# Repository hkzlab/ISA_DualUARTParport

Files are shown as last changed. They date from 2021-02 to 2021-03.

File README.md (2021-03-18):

# Dual UART + Parallel port ISA adapter

## Introduction

This board adds a parallel port and two serial (RS232) ports to computers with a free ISA slot.

The schematics of this board is heavily inspired by the parallel port schematics found in the IBM 5150 Technical Reference, with just a few
changes (IRQ level triggering and configurable port directionality) and by Sergey's floppy/serial controller.

Both serial ports and the parallel port addressing/IRQs are configurable.

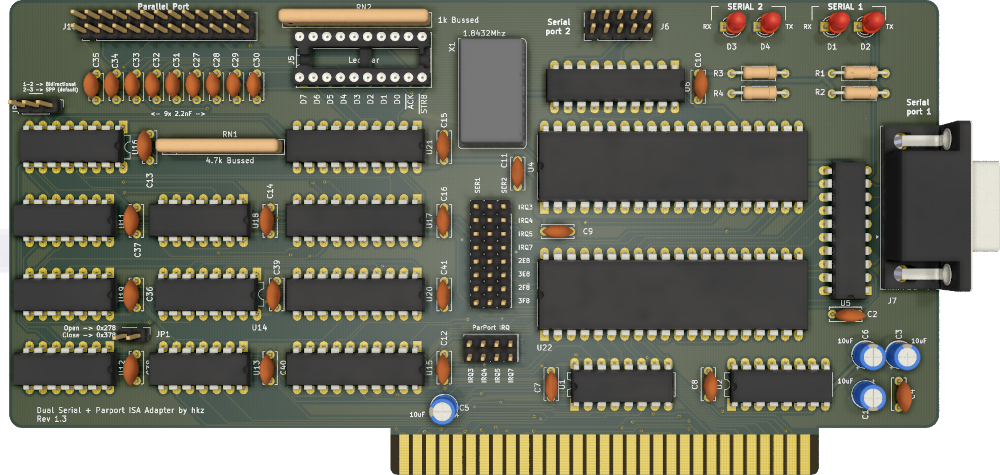
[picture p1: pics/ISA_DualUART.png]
Rev. 1.3 PCB


### Disclaimer

I take NO responsibility for what happens if you decide to build and use this card. Your computer might crash, catch fire or be destroyed in other nasty ways.
Also, as this card is mostly based on the work of others, You're encourauged to take what you deem fit from this, and use it in your projects!

## Configuration

### Parallel port

#### Addressing

- 0x278: Leave JP1 open
- 0x378: Close JP1

#### IRQ

Parallel port interrupt number can be selected by placing a single vertical jumper on the **ParPort IRQ** block.

For example, a jumper placed on the last column of that block, will set the IRQ for the parallel port to number 7.

#### Directionality

The parallel port can be configured as an old style 4bit, monodirectional, parallel port by jumpering pins 2-3 of JP2.
PS/2 style bidirectional port can be configured by jumpering pins 1-2.

### Serial ports

IRQ and addressing of serial ports can be configured by properly jumpering the 3x8 jumper block at the center of the board.

IRQ selection is performed by the first 4 rows of the block: placing an horizontal jumper between columns 1-2 will select IRQ for the first serial port, between columns 2-3 will select
the IRQ for the second serial port.

The same principle applies for the IO address, selected by the last 4 rows of the block: jumpers between column 1-2 will select an address for port 1, and between column 2-3 for port 2.

#### Example

To select IO at 0x3F8 and IRQ4 for port 1, connect a jumper on 2nd row, first two columns, and another jumper on 8th row, column 1-2

## Bill of Materials

All ICs are in DIP package.

- 4x ~2.2k 1/4W resistors (**optional**, R1-R4). **These resistors will be on the TTL RX/TX lines**. To avoid loading them too much, use high-brightness leds and the highest resistor value you can use that still gives enough brightness!
- 4x 3mm LEDs (2x for UART RX indicators, 2x for TX) (**optional**)
- 1x 1.8432Mhz oscillator. DIP14 or DIP8
- 1x 8x4.7k bussed resistor array (9 pin)
- 1x 10x1.5k bussed resistor array (11 pin) (**optional**)
- 1x 10x LED bar, DIP20 (**optional**, socket this!)
- 8x 2.2nF / 25V ceramic capacitors, 5mm pitch
- 18x 100nF / 50v ceramic capacitors, 5mm pitch
- 4x 10uF / 50v electrolytic caps
- 2x 16C550 UARTs (16C450/16C650/16C750 should work, but are untested) in DIP40 format
- 2x 74HCT/LS138
- 2x 75C185
- 1x 74LS245
- 1x 74LS240
- 1x 74LS374
- 1x 74LS244
- 1x 74LS02
- 1x 74LS155
- 1x 74LS05
- 1x 74LS174
- 1x 74LS30
- 1x 74LS125
- 1x 74LS86
- 1x 2x13 pin header, 2.54mm
- 1x 2x4 pin header, 2.54mm
- 1x 2x8 pin header, 2.54mm
- 1x 1x8 pin header, 2.54mm
- 1x 1x2 pin header, 2.54mm
- 1x 1x3 pin header, 2.54mm
- 1x DB9 male, right angle, PCB mount (http://www.mouser.com/search/refine.aspx?Keyword=806-K22X-E9P-NJ15-99)
- 1x ISA card bracket - Keystone 9200-1 (http://www.mouser.com/ProductDetail/Keystone-Electronics/9200-1/?qs=sGAEpiMZZMsQtlBhqKq43VLJ3wppkop5) 

## Building notes

I **strongly advise AGAINST** soldering the LED bar for the parallel port: **socket it!** It is useful for debugging or to get some blinkenlights, but it loads the data pins, and some devices connected to the port might not like it. Socketing it will allow for a quick removal in case it becomes necessary.

RN2 depends on how bright you wish the LED bar to be, and how much load you want to put on the parallel port data pins. I usually fit an 1.5k resistor array.

## Credits

Thanks to [Sergey](http://www.malinov.com/Home/sergeys-projects) for all his projects!

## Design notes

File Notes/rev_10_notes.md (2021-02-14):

# Revision 1.0 Notes

## Parallel port header

The parallel port header is not standard in revision 1.0, and requires a custom cable to be made.
The pinout uses an odd-even scheme. A schematic looking at the male header on the front of the board:

```text
25 23 21 19 17 15 13 11 09 07 05 03 01
26 24 22 20 18 16 14 12 10 08 06 04 02
```

## Parallel port IRQ

Revision 1.0 board follows the IBM 5150 Technical Manual, but the parallel port presented there has a now out-of-standard IRQ triggering system. To bring it back in line with the now standard behavior, perform the following modification:

1. Cut the trace leading to pin 12 of U19. The best place to do this is right under the solder pad. Pay attention not to interrupt the trace hidden under the silkscreen
2. Bridge pin 12 of U19 with pin 13 of U12 with a piece of wire
3. Solder a pull-up resistor (4.7k ohm) between pin 12 of U19 and VCC (use the filter cap nearby).

Picture for reference.

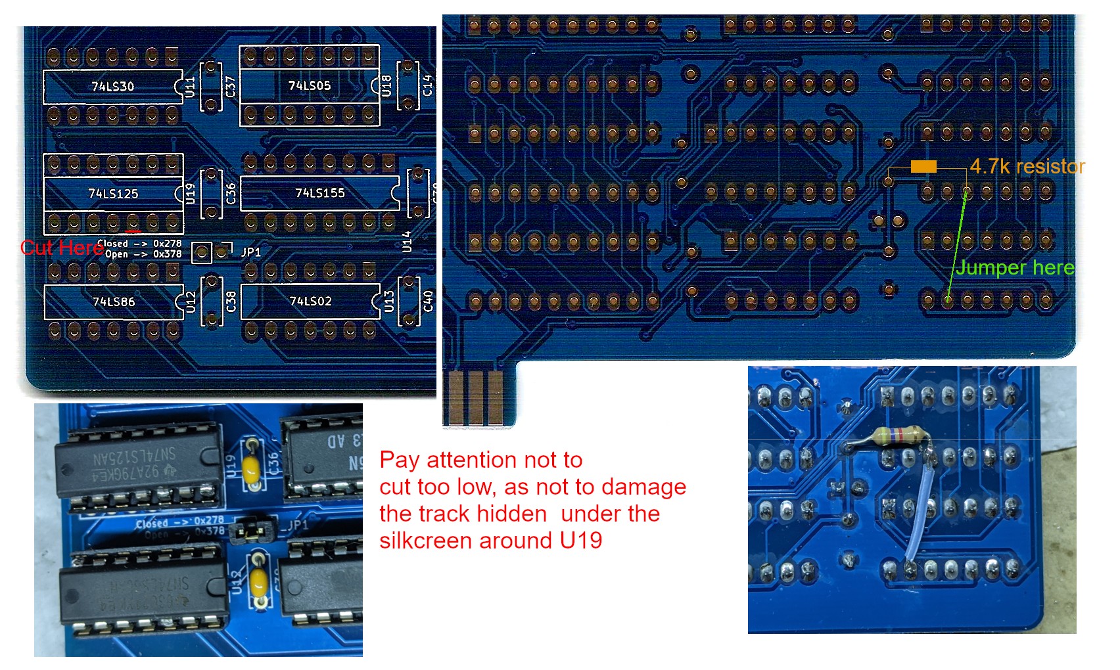
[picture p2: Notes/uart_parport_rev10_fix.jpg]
IRQ Mod


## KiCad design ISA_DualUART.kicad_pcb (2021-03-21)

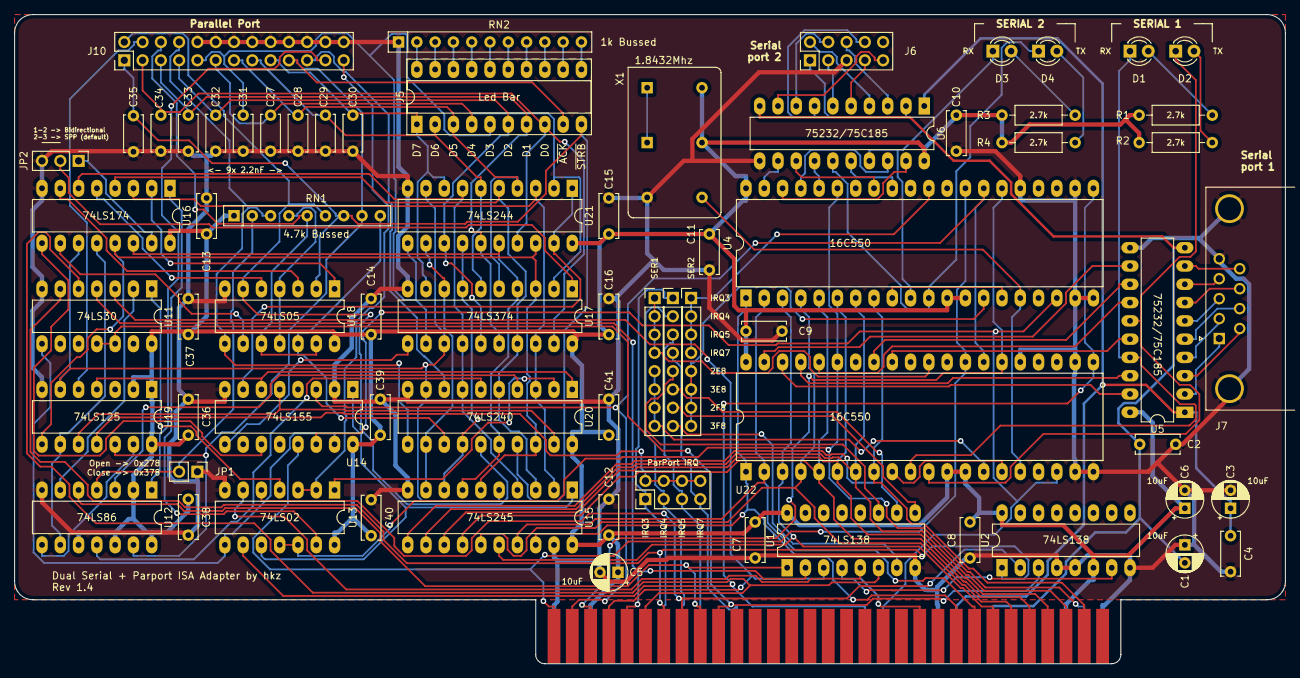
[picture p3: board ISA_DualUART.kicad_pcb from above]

Board: 2 copper layers, 176.5 x 90.2 mm, 70 parts (0 on the bottom side), 138 nets.

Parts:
C1, C3, C5, C6: 10uF; CP_Radial_D5.0mm_P2.50mm
C2, C4, C7, C8, C9, C10, C11, C12, C13, C14, C15, C16, C36, C37, C38, C39, C40, C41: 100nF; C_Disc_D6.0mm_W2.5mm_P5.00mm
C27, C28, C29, C30, C31, C32, C33, C34, C35: 2.2nF; C_Disc_D5.0mm_W2.5mm_P5.00mm
D1: LED RX1; LED_D3.0mm
D2: LED TX1; LED_D3.0mm
D3: LED RX2; LED_D3.0mm
D4: LED TX2; LED_D3.0mm
J1: ISA BUS; Conn_Edge_PCB_ISA8
J2: ADDR_IRQ; PinHeader_1x08_P2.54mm_Vertical
J3: UART1_SEL; PinHeader_1x08_P2.54mm_Vertical
J4: UART2_SEL; PinHeader_1x08_P2.54mm_Vertical
J5: Parallel Port LEDs; DIP-20_W7.62mm_Socket_LongPads
J6: Serial 2 IDC; PinHeader_2x05_P2.54mm_Vertical
J7: Serial 1 DB9; DSUB-9_Male_Horizontal_P2.77x2.84mm_EdgePinOffset7.70mm_Hou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
J9: Parport IRQ Select; PinHeader_2x04_P2.54mm_Vertical
J10: Parallel Port; PinHeader_2x13_P2.54mm_Vertical
JP1: Address selection; PinHeader_1x02_P2.54mm_Vertical
JP2: Parport type; PinHeader_1x03_P2.54mm_Vertical
R1, R2, R3, R4: 2.7k; R_Axial_DIN0207_L6.3mm_D2.5mm_P10.16mm_Horizontal
RN1: 4.7k; R_Array_SIP9
RN2: 1k; R_Array_SIP11
U1, U2: 74LS138; DIP-16_W7.62mm_LongPads
U4, U22: 16550; DIP-40_W15.24mm_LongPads
U5, U6: GD75232N; DIP-20_W7.62mm_LongPads
U11: 74LS30; DIP-14_W7.62mm_LongPads
U12: 74LS86; DIP-14_W7.62mm_LongPads
U13: 74LS02; DIP-14_W7.62mm_LongPads
U14: 74LS155; DIP-16_W7.62mm_LongPads
U15: 74LS245; DIP-20_W7.62mm_LongPads
U16: 74LS174; DIP-16_W7.62mm_LongPads
U17: 74LS374; DIP-20_W7.62mm_LongPads
U18: 74LS05; DIP-14_W7.62mm_LongPads
U19: 74LS125; DIP-14_W7.62mm_LongPads
U20: 74LS240; DIP-20_W7.62mm_LongPads
U21: 74LS244; DIP-20_W7.62mm_LongPads
X1: 1.8432Mhz; Oscillator_DIP-14-8

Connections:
+12V: C3.1, C4.1, J1.9, U5.1, U6.1
-12V: C1.2, C2.2, J1.7, U5.10, U6.10
/0x2E8: J2.5, U1.11
/0x2F8: J2.7, U1.9
/0x3E8: J2.6, U1.10
/0x3F8: J2.8, U1.7
/A0: J1.62, U4.28, U14.13, U22.28
/A1: J1.61, U4.27, U14.3, U22.27
/A2: J1.60, U4.26, U22.26
/A3: J1.59, U1.3, U11.3
/A4: J1.58, U1.2, U11.4
/A5: J1.57, U1.6, U11.5
/A6: J1.56, U2.1, U11.6
/A7: J1.55, U2.2, U13.5
/A8: J1.54, U1.1, U12.5
/A9: J1.53, U2.3, U11.11, U11.12
/AEN: J1.42, U1.5, U13.6
/D0: J1.40, U4.1, U15.18, U22.1
/D1: J1.39, U4.2, U15.17, U22.2
/D2: J1.38, U4.3, U15.16, U22.3
/D3: J1.37, U4.4, U15.15, U22.4
/D4: J1.36, U4.5, U15.14, U22.5
/D5: J1.35, U4.6, U15.13, U22.6
/D6: J1.34, U4.7, U15.12, U22.7
/D7: J1.33, U4.8, U15.11, U22.8
/IRQ3: J1.25, J2.1, J9.1
/IRQ4: J1.24, J2.2, J9.3
/IRQ5: J1.23, J2.3, J9.5
/IRQ7: J1.21, J2.4, J9.7
/PARPORT_BD0: U15.2, U16.3, U17.18, U20.3, U21.3
/PARPORT_BD1: U15.3, U16.4, U17.17, U20.5, U21.5
/PARPORT_BD2: U15.4, U16.6, U17.14, U20.7, U21.7
/PARPORT_BD3: U15.5, U16.11, U17.13, U19.6, U20.9, U21.9
/PARPORT_BD4: U15.6, U16.13, U17.3, U19.8, U20.18, U21.18
/PARPORT_BD5: U15.7, U16.14, U17.4, U20.16, U21.16
/PARPORT_BD6: U15.8, U17.7, U20.14, U21.14
/PARPORT_BD7: U15.9, U17.8, U20.12, U21.12
/PARPORT_BUSY: J10.21, U20.8
/PARPORT_DATA0: C34.1, J5.8, J10.3, U17.19, U21.17
/PARPORT_DATA1: C33.1, J5.7, J10.5, U17.16, U21.15
/PARPORT_DATA2: C32.1, J5.6, J10.7, U17.15, U21.13
/PARPORT_DATA3: C31.1, J5.5, J10.9, U17.12, U21.11
/PARPORT_DATA4: C27.1, J5.4, J10.11, U17.2, U21.2
/PARPORT_DATA5: C28.1, J5.3, J10.13, U17.5, U21.4
/PARPORT_DATA6: C29.1, J5.2, J10.15, U17.6, U21.6
/PARPORT_DATA7: C30.1, J5.1, J10.17, U17.9, U21.8
/PARPORT_DIR: JP2.1, U16.15
/PARPORT_IRQ: U12.11, U20.6
/PARPORT_IRQEN: U12.9, U16.12, U19.9
/PARPORT_PE: J10.23, U12.1
/PARPORT_R: U13.10, U14.1, U15.1
/PARPORT_RPA: U14.7, U21.1, U21.19
/PARPORT_RPB: U14.6, U19.4, U20.1
/PARPORT_RPC: U14.5, U19.10, U20.19
/PARPORT_SLCT: J10.25, U13.2, U13.3
/PARPORT_WPA: U14.9, U17.11
/PARPORT_WPC: U14.11, U16.9
/RESETDRV: J1.2, U4.35, U13.11, U13.12, U22.35
/RN_1: JP1.2, RN1.2, U12.4
/RN_2: J10.8, RN1.3, U18.8, U20.11
/RN_3: RN1.4, U18.4, U18.11
/RN_4: J10.6, RN1.5, U18.10, U18.13
/RN_5: J10.2, RN1.6, U18.6, U20.15
/RN_6: C35.2, J5.10, J10.1, RN1.7, U18.2, U20.17
/RN_7: J5.9, J10.19, RN1.8, U12.13, U19.12
/RN_8: RN1.9, U18.12, U20.13
/RS232_1_CTS: J7.8, U5.7
/RS232_1_DCD: J7.1, U5.2
/RS232_1_DSR: J7.6, U5.3
/RS232_1_DTR: J7.4, U5.8
/RS232_1_RI: J7.9, U5.9
/RS232_1_RTS: J7.7, U5.5
/RS232_1_RX: J7.2, U5.4
/RS232_1_TX: J7.3, U5.6
/RS232_2_CTS: J6.8, U6.7
/RS232_2_DCD: J6.1, U6.2
/RS232_2_DSR: J6.6, U6.3
/RS232_2_DTR: J6.4, U6.8
/RS232_2_RI: J6.9, U6.9
/RS232_2_RTS: J6.7, U6.5
/RS232_2_RX: J6.2, U6.4
/RS232_2_TX: J6.3, U6.6
/SER_CLK: U4.16, U22.16, X1.8
/SIN_1: D1.1, U5.17, U22.10
/SIN_2: D3.1, U4.10, U6.17
/SOUT_1: D2.1, U5.15, U22.11
/SOUT_2: D4.1, U4.11, U6.15
/UART1_IRQ: J3.1, J3.2, J3.3, J3.4, U22.30
/UART2_IRQ: J4.1, J4.2, J4.3, J4.4, U4.30
/~CTS_1: U5.14, U22.36
/~CTS_2: U4.36, U6.14
/~DCD_1: U5.19, U22.38
/~DCD_2: U4.38, U6.19
/~DSR_1: U5.18, U22.37
/~DSR_2: U4.37, U6.18
/~DTR_1: U5.13, U22.33
/~DTR_2: U4.33, U6.13
/~IOR: J1.14, U4.21, U13.9, U22.21
/~IOW: J1.13, U4.18, U14.14, U22.18
/~PARPORT_ERROR: J10.4, U19.5
/~PARPORT_IRQEN: U12.8, U19.13
/~PARPORT_RESET: U13.13, U16.1
/~RI_1: U5.12, U22.39
/~RI_2: U4.39, U6.12
/~RTS_1: U5.16, U22.32
/~RTS_2: U4.32, U6.16
/~UART1_CS: J3.5, J3.6, J3.7, J3.8, U22.14
/~UART2_CS: J4.5, J4.6, J4.7, J4.8, U4.14
GND: C1.1, C2.1, C3.2, C4.2, C5.2, C6.2, C7.2, C8.2, C9.2, C10.2, C11.2, C12.1, C13.2, C14.2, C15.2, C16.2, C27.2, C28.2, C29.2, C30.2, C31.2, C32.2, C33.2, C34.2, C35.1, C36.2, C37.2, C38.2, C39.2, C40.2, C41.2, J1.1, J1.10, J1.31, J6.5, J7.0, J7.5, J10.10, J10.12, J10.14, J10.16, J10.18, J10.20, J10.22, J10.24, J10.26, JP1.1, JP2.3, RN2.1, U1.8, U2.4, U2.5, U2.8, U4.19, U4.20, U4.22, U4.25, U5.11, U6.11, U11.7, U12.7, U13.7, U14.2, U14.8, U15.10, U15.19, U16.8, U17.10, U18.7, U19.7, U20.10, U21.10, U22.19, U22.20, U22.22, U22.25, X1.7
unnamed: D1.2, R1.1
unnamed: D2.2, R2.1
unnamed: D3.2, R3.1
unnamed: D4.2, R4.1
unnamed: J5.11, RN2.11
unnamed: J5.12, RN2.10
unnamed: J5.13, RN2.9
unnamed: J5.14, RN2.8
unnamed: J5.15, RN2.7
unnamed: J5.16, RN2.6
unnamed: J5.17, RN2.5
unnamed: J5.18, RN2.4
unnamed: J5.19, RN2.3
unnamed: J5.20, RN2.2
unnamed: J9.2, J9.4, J9.6, J9.8, U19.11
unnamed: JP2.2, U17.1
unnamed: U1.4, U2.7
unnamed: U4.9, U4.15
unnamed: U11.1, U13.4
unnamed: U11.2, U12.6
unnamed: U11.8, U13.8, U14.15
unnamed: U12.3, U20.4
unnamed: U13.1, U20.2
unnamed: U16.2, U18.1
unnamed: U16.5, U18.5
unnamed: U16.7, U18.3
unnamed: U16.10, U18.9
unnamed: U22.9, U22.15
VCC: C5.1, C6.1, C7.1, C8.1, C9.1, C10.1, C11.1, C12.2, C13.1, C14.1, C15.1, C16.1, C36.1, C37.1, C38.1, C39.1, C40.1, C41.1, J1.3, J1.29, R1.2, R2.2, R3.2, R4.2, RN1.1, U1.16, U2.6, U2.16, U4.12, U4.13, U4.40, U5.20, U6.20, U11.14, U12.2, U12.10, U12.12, U12.14, U13.14, U14.16, U15.20, U16.16, U17.20, U18.14, U19.1, U19.2, U19.14, U20.20, U21.20, U22.12, U22.13, U22.40, X1.14

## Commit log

2021-01-17 Add submodules
    [ISA_DualUART.kicad_pcb, ISA_DualUART.sch]
2021-01-17 Add footprints and components
2021-01-17 Add custom module and new oscillator footprint
    [ISA_DualUART.sch]
2021-01-17 Begin adding components
    [ISA_DualUART.sch]
2021-01-17 Added all the required ICs
    [ISA_DualUART.sch]
2021-01-17 Begin wiring UARTs
    [ISA_DualUART.sch]
2021-01-17 First revision of the schematic
    [ISA_DualUART.kicad_pcb, ISA_DualUART.sch]
2021-01-18 Add gameport circuit
    [ISA_DualUART.sch]
2021-01-18 Add gameport components
    [ISA_DualUART.sch]
2021-01-19 Add more components of the parallel port
    [ISA_DualUART.sch]
2021-01-19 More components of the parallel port
    [ISA_DualUART.sch]
2021-01-19 First version of schematic for multifunction isa board
    [ISA_DualUART.kicad_pcb, ISA_DualUART.sch]
2021-01-21 Fix RPB line
    [ISA_DualUART.kicad_pcb, ISA_DualUART.sch]
2021-01-25 Begin organizing the board
    [ISA_DualUART.kicad_pcb, ISA_DualUART.sch]
2021-01-29 First model of the board
    [ISA_DualUART-backup.sch, ISA_DualUART.kicad_pcb, ISA_DualUART.sch]
2021-01-29 Move some silk
    [ISA_DualUART.kicad_pcb]
2021-01-29 Moved around some components
    [ISA_DualUART.kicad_pcb]
2021-01-29 Move some components
    [ISA_DualUART.kicad_pcb]
2021-01-29 Chane connector
    [ISA_DualUART.kicad_pcb, ISA_DualUART.sch]
2021-01-29 Update PCB
    [ISA_DualUART.kicad_pcb]
2021-01-30 Add text and generate gerbers
    [ISA_DualUART.kicad_pcb, ISA_DualUART.sch]
2021-02-05 Change socket footprint to normal DIP
    [ISA_DualUART.kicad_pcb, ISA_DualUART.sch]
2021-02-05 Fix silkscreen
    [ISA_DualUART.kicad_pcb, ISA_DualUART.sch]
2021-02-05 Rerouted, now serial connector has shield to gnd
    [ISA_DualUART.kicad_pcb, ISA_DualUART.sch]
2021-02-06 Slightly better silkscreen
    [ISA_DualUART.kicad_pcb]
2021-02-08 Rewire parallel port connector
    [ISA_DualUART.sch]
2021-02-08 Rerouted card
    [ISA_DualUART.kicad_pcb]
2021-02-08 Changed organization of parport connector
    [ISA_DualUART.kicad_pcb, ISA_DualUART.sch]
2021-02-09 Invert IRQ sensing to conform to AT specs
    [ISA_DualUART.kicad_pcb, ISA_DualUART.sch]
2021-02-10 Reworked the board, added LED indicators for parport
    [ISA_DualUART.kicad_pcb, ISA_DualUART.sch]
2021-02-10 Fixed silkscreen
    [ISA_DualUART.kicad_pcb]
2021-02-10 Another silkscreen fix
    [ISA_DualUART.kicad_pcb]
2021-02-10 Rotate parport and serial headers
    [ISA_DualUART.kicad_pcb]
2021-02-10 Updated schematics
    [ISA_DualUART.sch]
2021-02-11 Forgot gerbers for rev 1.1
2021-02-11 Update silkscreen
    [ISA_DualUART.kicad_pcb]
2021-02-23 Update solder mask
    [ISA_DualUART.kicad_pcb, ISA_DualUART.sch]
2021-03-10 Minor silkscreen fix
    [ISA_DualUART.kicad_pcb]
2021-03-10 Other minor silkscreen fixes
    [ISA_DualUART-backup.sch, ISA_DualUART.kicad_pcb]
2021-03-10 More silkscreen fixes
    [ISA_DualUART.kicad_pcb]
2021-03-10 Add BOM and resized pic
2021-03-10 Add missing caps from BOM
2021-03-21 Slight changes to silkscreen
    [ISA_DualUART.kicad_pcb, ISA_DualUART.sch]
2021-03-21 Mark revision as 1.4
    [ISA_DualUART.kicad_pcb]
2021-11-09 Update kicad url
